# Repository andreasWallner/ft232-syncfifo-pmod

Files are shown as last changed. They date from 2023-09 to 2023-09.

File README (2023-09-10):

**WIP**

# iceBreaker

References:
- https://github.com/icebreaker-fpga/icebreaker

# Arty-A7

References:
- https://digilent.com/reference/programmable-logic/arty-a7/reference-manual
- https://datasheet.octopart.com/XC7K160T-1FBG676I-Xilinx-datasheet-138898721.pdf#page=70
- https://www.xilinx.com/support/packagefiles/a7packages/xc7a35tcsg324pkg.txt
- https://www.xilinx.com/support/packagefiles/a7packages/xc7a100tcsg324pkg.txt

Pinout

    JC
    
    U12  IO_L20P_T3_A08_D24_14         3                  14    NA            NA                  HR        NA
    V12  IO_L20N_T3_A07_D23_14         3                  14    NA            NA                  HR        NA
    V10  IO_L21P_T3_DQS_14             3                  14    NA            NA                  HR        NA
    V11  IO_L21N_T3_DQS_A06_D22_14     3                  14    NA            NA                  HR        NA
    U14  IO_L22P_T3_A05_D21_14         3                  14    NA            NA                  HR        NA
    V14  IO_L22N_T3_A04_D20_14         3                  14    NA            NA                  HR        NA
    T13  IO_L23P_T3_A03_D19_14         3                  14    NA            NA                  HR        NA
    U13  IO_L23N_T3_A02_D18_14         3                  14    NA            NA                  HR        NA
    
    JB
    
    E15  IO_L11P_T1_SRCC_15            1                  15    NA            NA                  HR        NA
    E16  IO_L11N_T1_SRCC_15            1                  15    NA            NA                  HR        NA
    D15  IO_L12P_T1_MRCC_15            1                  15    NA            NA                  HR        NA
    C15  IO_L12N_T1_MRCC_15            1                  15    NA            NA                  HR        NA
    J17  IO_L23P_T3_FOE_B_15           3                  15    NA            NA                  HR        NA
    J18  IO_L23N_T3_FWE_B_15           3                  15    NA            NA                  HR        NA
    K15  IO_L24P_T3_RS1_15             3                  15    NA            NA                  HR        NA
    J15  IO_L24N_T3_RS0_15             3                  15    NA            NA                  HR        NA

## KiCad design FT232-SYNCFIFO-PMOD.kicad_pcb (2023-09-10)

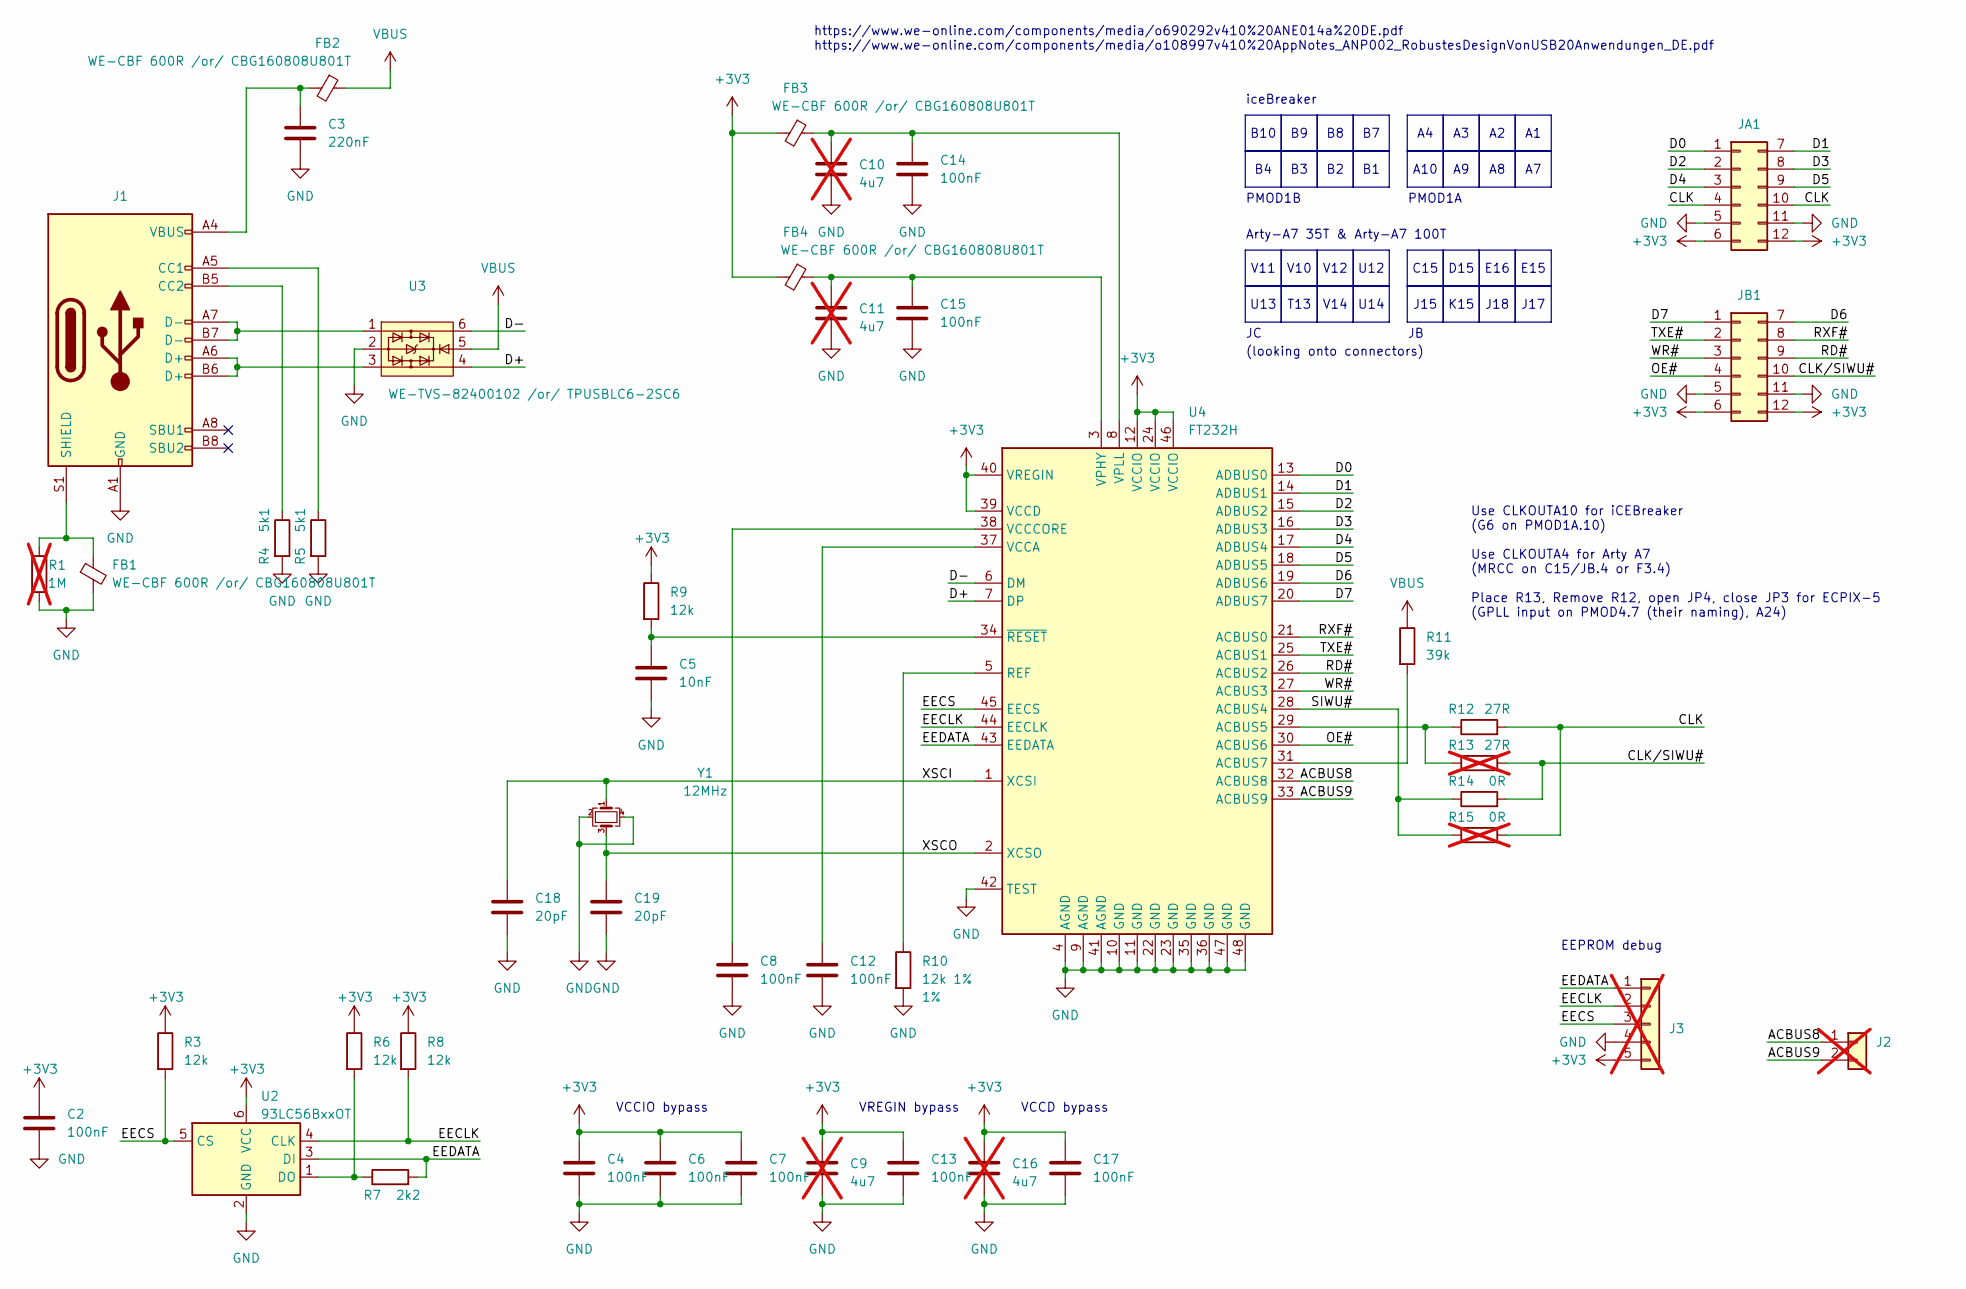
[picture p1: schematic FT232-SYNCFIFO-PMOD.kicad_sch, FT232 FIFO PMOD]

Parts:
C2, C4, C6, C7, C8, C12, C13, C14, C15, C17: 100nF; C_0402_1005Metric; LCSC C1525
C3: 220nF; C_0603_1608Metric; LCSC C16772
C5: 10nF; C_0402_1005Metric; LCSC C15195
C9, C10, C11, C16: 4u7; C_0402_1005Metric; not fitted
C18, C19: 20pF; C_0402_1005Metric; LCSC C1525
FB1, FB2, FB3, FB4: WE-CBF 600R /or/ CBG160808U801T; L_0603_1608Metric; LCSC C98500
J1: WR-COM USB 2.0 Type C Receptacle Horizontal SMT /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; wuerth_629722000214; LCSC C3001293
J2: dnp; PinHeader_1x02_P2.54mm_Vertical; not fitted
J3: Conn_01x05; PinHeader_1x05_P2.54mm_Vertical; not fitted
JA1: TE 825457-6; PinHeaderPMOD_2x06_P2.54mm_Horizontal; LCSC C60565
JB1: TE 825457-6; PinHeaderPMOD_2x06_P2.54mm_Horizontal; LCSC C60565
R1: 1M; R_0402_1005Metric; LCSC C102751; not fitted
R3, R6, R8, R9: 12k; R_0402_1005Metric; LCSC C25752
R4, R5: 5k1; R_0402_1005Metric; LCSC C409700
R7: 2k2; R_0402_1005Metric; LCSC C25879
R10: 12k 1%; R_0402_1005Metric; Tolerance 1%; LCSC C269386
R11: 39k; R_0402_1005Metric; LCSC C25752
R12: 27R; R_0402_1005Metric; LCSC C140174
R13: 27R; R_0402_1005Metric; LCSC C140174; not fitted
R14: 0R; R_0402_1005Metric; LCSC C279984
R15: 0R; R_0402_1005Metric; LCSC C279984; not fitted
U2: 93LC56BxxOT; SOT-23-6; LCSC C190271
U3: WE-TVS-82400102 /or/ TPUSBLC6-2SC6; SOT-23-6; LCSC C558442
U4: FT232H; QFN-48-1EP_8x8mm_P0.5mm_EP6.2x6.2mm; Farnell 1870925
Y1: 12MHz; Crystal_SMD_3225-4Pin_3.2x2.5mm_HandSoldering; LCSC C654952

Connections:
+3V3: C2.1, C4.1, C6.1, C7.1, C9.1, C13.1, C16.1, C17.1, FB3.2, FB4.2, J3.5, JA1.6, JA1.12, JB1.6, JB1.12, R3.1, R6.1, R8.1, R9.1, U2.6 (VCC), U4.12 (VCCIO), U4.24 (VCCIO), U4.39 (VCCD), U4.40 (VREGIN), U4.46 (VCCIO)
/ACBUS8: J2.1, U4.32 (ACBUS8)
/ACBUS9: J2.2, U4.33 (ACBUS9)
/CLK: JA1.4, JA1.10, R12.2, R15.2
/CLK/SIWU#: JB1.10, R13.1, R14.2
/D0: JA1.1, U4.13 (ADBUS0)
/D1: JA1.7, U4.14 (ADBUS1)
/D2: JA1.2, U4.15 (ADBUS2)
/D3: JA1.8, U4.16 (ADBUS3)
/D4: JA1.3, U4.17 (ADBUS4)
/D5: JA1.9, U4.18 (ADBUS5)
/D6: JB1.7, U4.19 (ADBUS6)
/D7: JB1.1, U4.20 (ADBUS7)
/D+: U3.4, U4.7 (DP)
/D-: U3.6, U4.6 (DM)
/EECLK: J3.2, R8.2, U2.4 (CLK), U4.44 (EECLK)
/EECS: J3.3, R3.2, U2.5 (CS), U4.45 (EECS)
/EEDATA: J3.1, R7.2, U2.3 (DI), U4.43 (EEDATA)
/OE#: JB1.4, U4.30 (ACBUS6)
/RD#: JB1.9, U4.26 (ACBUS2)
/RXF#: JB1.8, U4.21 (ACBUS0)
/SIWU#: R14.1, R15.1, U4.28 (ACBUS4)
/TXE#: JB1.2, U4.25 (ACBUS1)
/WR#: JB1.3, U4.27 (ACBUS3)
/XSCI: C18.1, U4.1 (XCSI), Y1.1
/XSCO: C19.1, U4.2 (XCSO), Y1.3
GND: C2.2, C3.2, C4.2, C5.2, C6.2, C7.2, C8.2, C9.2, C10.2, C11.2, C12.2, C13.2, C14.2, C15.2, C16.2, C17.2, C18.2, C19.2, FB1.2, J1.A1 (GND), J1.A12 (GND), J1.B1 (GND), J1.B12 (GND), J3.4, JA1.5, JA1.11, JB1.5, JB1.11, R1.2, R4.2, R5.2, R10.2, U2.2 (GND), U3.2, U4.4 (AGND), U4.9 (AGND), U4.10 (GND), U4.11 (GND), U4.22 (GND), U4.23 (GND), U4.35 (GND), U4.36 (GND), U4.41 (AGND), U4.42 (TEST), U4.47 (GND), U4.48 (GND), Y1.2, Y1.4
unnamed: C3.1, FB2.2, J1.A4 (VBUS), J1.A9 (VBUS), J1.B4 (VBUS), J1.B9 (VBUS)
unnamed: J1.A5 (CC1), R5.1
unnamed: J1.B5 (CC2), R4.1
unnamed: J1.A6 (D+), J1.B6 (D+), U3.3
unnamed: J1.A7 (D-), J1.B7 (D-), U3.1
unnamed: FB1.1, J1.S1 (SHIELD), R1.1
unnamed: R6.2, R7.1, U2.1 (DO)
unnamed: R12.1, R13.2, U4.29 (ACBUS5)
unnamed: R11.2, U4.31 (ACBUS7)
unnamed: R10.1, U4.5 (REF)
unnamed: C12.1, U4.37 (VCCA)
unnamed: C8.1, U4.38 (VCCCORE)
unnamed: C11.1, C15.1, FB4.1, U4.3 (VPHY)
unnamed: C10.1, C14.1, FB3.1, U4.8 (VPLL)
unnamed: C5.1, R9.2, U4.34 (~RESET)
VBUS: FB2.1, R11.1, U3.5

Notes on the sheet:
D15
E15
K15
V12
V11
V10
A10
V14
C15
U12
J15
U13
J18
J17
U14
E16
T13
B10
Use CLKOUTA10 for iCEBreaker (G6 on PMOD1A.10) Use CLKOUTA4 for Arty A7 (MRCC on C15/JB.4 or F3.4) Place R13, Remove R12, open JP4, close JP3 for ECPIX-5 (GPLL input on PMOD4.7 (their naming), A24)
https://www.we-online.com/components/media/o690292v410%20ANE014a%20DE.pdf https://www.we-online.com/components/media/o108997v410%20AppNotes_ANP002_RobustesDesignVonUSB20Anwendungen_DE.pdf
VCCD bypass
VCCIO bypass
iceBreaker
(looking onto connectors)
PMOD1A
VREGIN bypass
PMOD1B
Arty-A7 35T & Arty-A7 100T
EEPROM debug

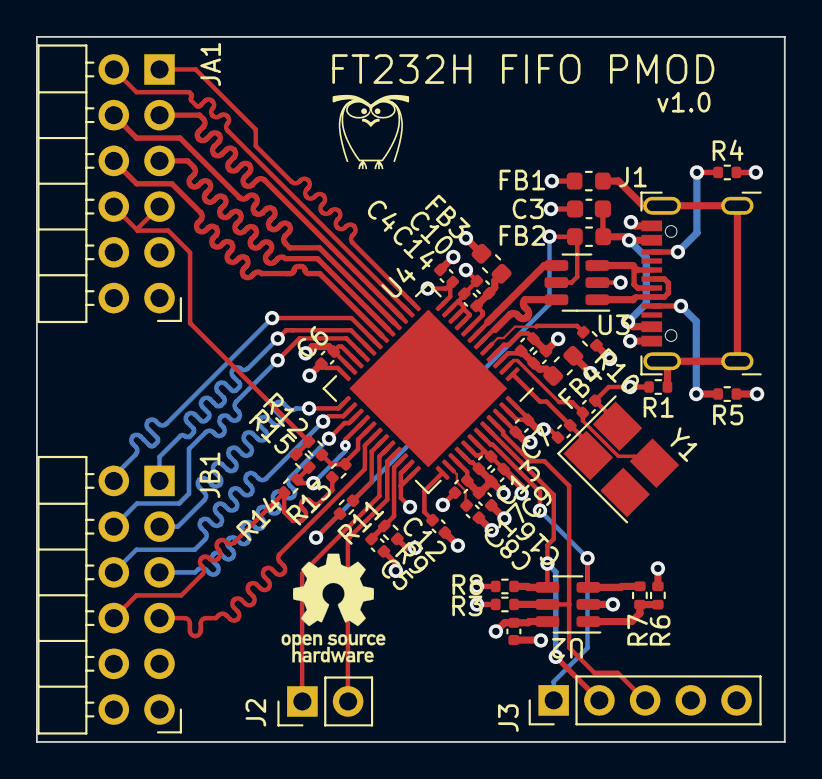
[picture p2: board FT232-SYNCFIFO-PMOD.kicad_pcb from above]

Board: 4 copper layers, 41.5 x 39.2 mm, 45 parts (0 on the bottom side), 43 nets.
